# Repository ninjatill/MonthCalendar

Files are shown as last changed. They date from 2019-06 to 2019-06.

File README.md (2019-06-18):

# Month Calendar
A daily gold star system, one month at a time. Inspired by the [Every Day Calendar](https://www.kickstarter.com/projects/simonegiertz/the-every-day-calendar), this is a compact version that has 48 total touch pads.

I saw the Every Day Calendar (EDC) referenced on the Particle forums. It sounded like a great idea and I needed way to track if I took my daily allergy pill. However, the EDC is very large and therefore expensive to manufacture. It is also a big challenge (and cost) to read 365 touch inputs and control 365 LEDs (especially if made to be RGB or varying intensity). I also thought the functionality could be expanded beyond just turning an LED on to indicate completion. By the time I got around to designing my own version, the Kickstarter campain had closed and there were no resouces made available via open source yet. So I designed it all from scratch.

My Design Criteria:
- Should be small enough to fit inside a medicine cabinet or mounted on limited wall space in a bathroom.
- Should still be able to track every day of the year.
- Should record and track progress and report it to the cloud for review.
- Should be able to track multiple users (like a husband and wife pair).
- Should use capacitive touch (seems more robust and it's something new to learn).
- Should have colored LEDs that shine up through the PCB (similar to the static LED color on the EDC). Color can be used for:
  - Indicating missed days with red (or some alternative) color.
  - Showing fancy animations to entice interaction/completion.
  - Indicating separate users and tasks via differing color schemes.

Additional considerations (some after starting the design):
- There's no need to have the LEDs on all the time. Perhaps some sort of human presense detector can be incorporated to only turn on the LEDs when someone is near the system.
- If this is in a bathroom, where most people start their day, it would be benificial to act as a calendar to indicate what is the current day.
- Because of the modularity, the top touch plate (described below) could be swapped out for different configurations or locales. It might be a benifit (or neccessary) to add non-volitile storage to the touch plate to identify hardware revisions, serial numbers, locales, layout changes, etc.
- To minimize light bleed between indicators I will fabricate a 3D-printed light collimator.
- Neopixels are the obvious choice for RGB LEDs because they are chainable and have their own internal controller. I think the RGBW chips would be best so you can stil get the white LED "classic" look. Each RGBW Neopixel can draw up to 80 mA and with 48 Neopixels, the max current draw is 3.82 A. If adding day of week indicators, then with 53 Neopixels the current max current draw is up to 4.24 A. Although real-world applications would probably not push more than 2 A, the power draw is still significant and the power supply will have to be chosen appropriately. Additionally, there may have to be firmware constraints in place to prevent over taxing the power supply.

The initial design uses 2 PCBs connected via pin headers. The bottom PCB contains all the controller hardware and LEDs. The Top PCB is merely a touch plate containing all the capacitive touch pads. The microcontroller is inserted on the back-side of the controller PCB as well as the power entry ports. The PCBs will be mounted in a 3D printed case. 

# WARNING: This project is in development!
### Only v0.x files have been uploaded for review and all designs are subject to change without notice.

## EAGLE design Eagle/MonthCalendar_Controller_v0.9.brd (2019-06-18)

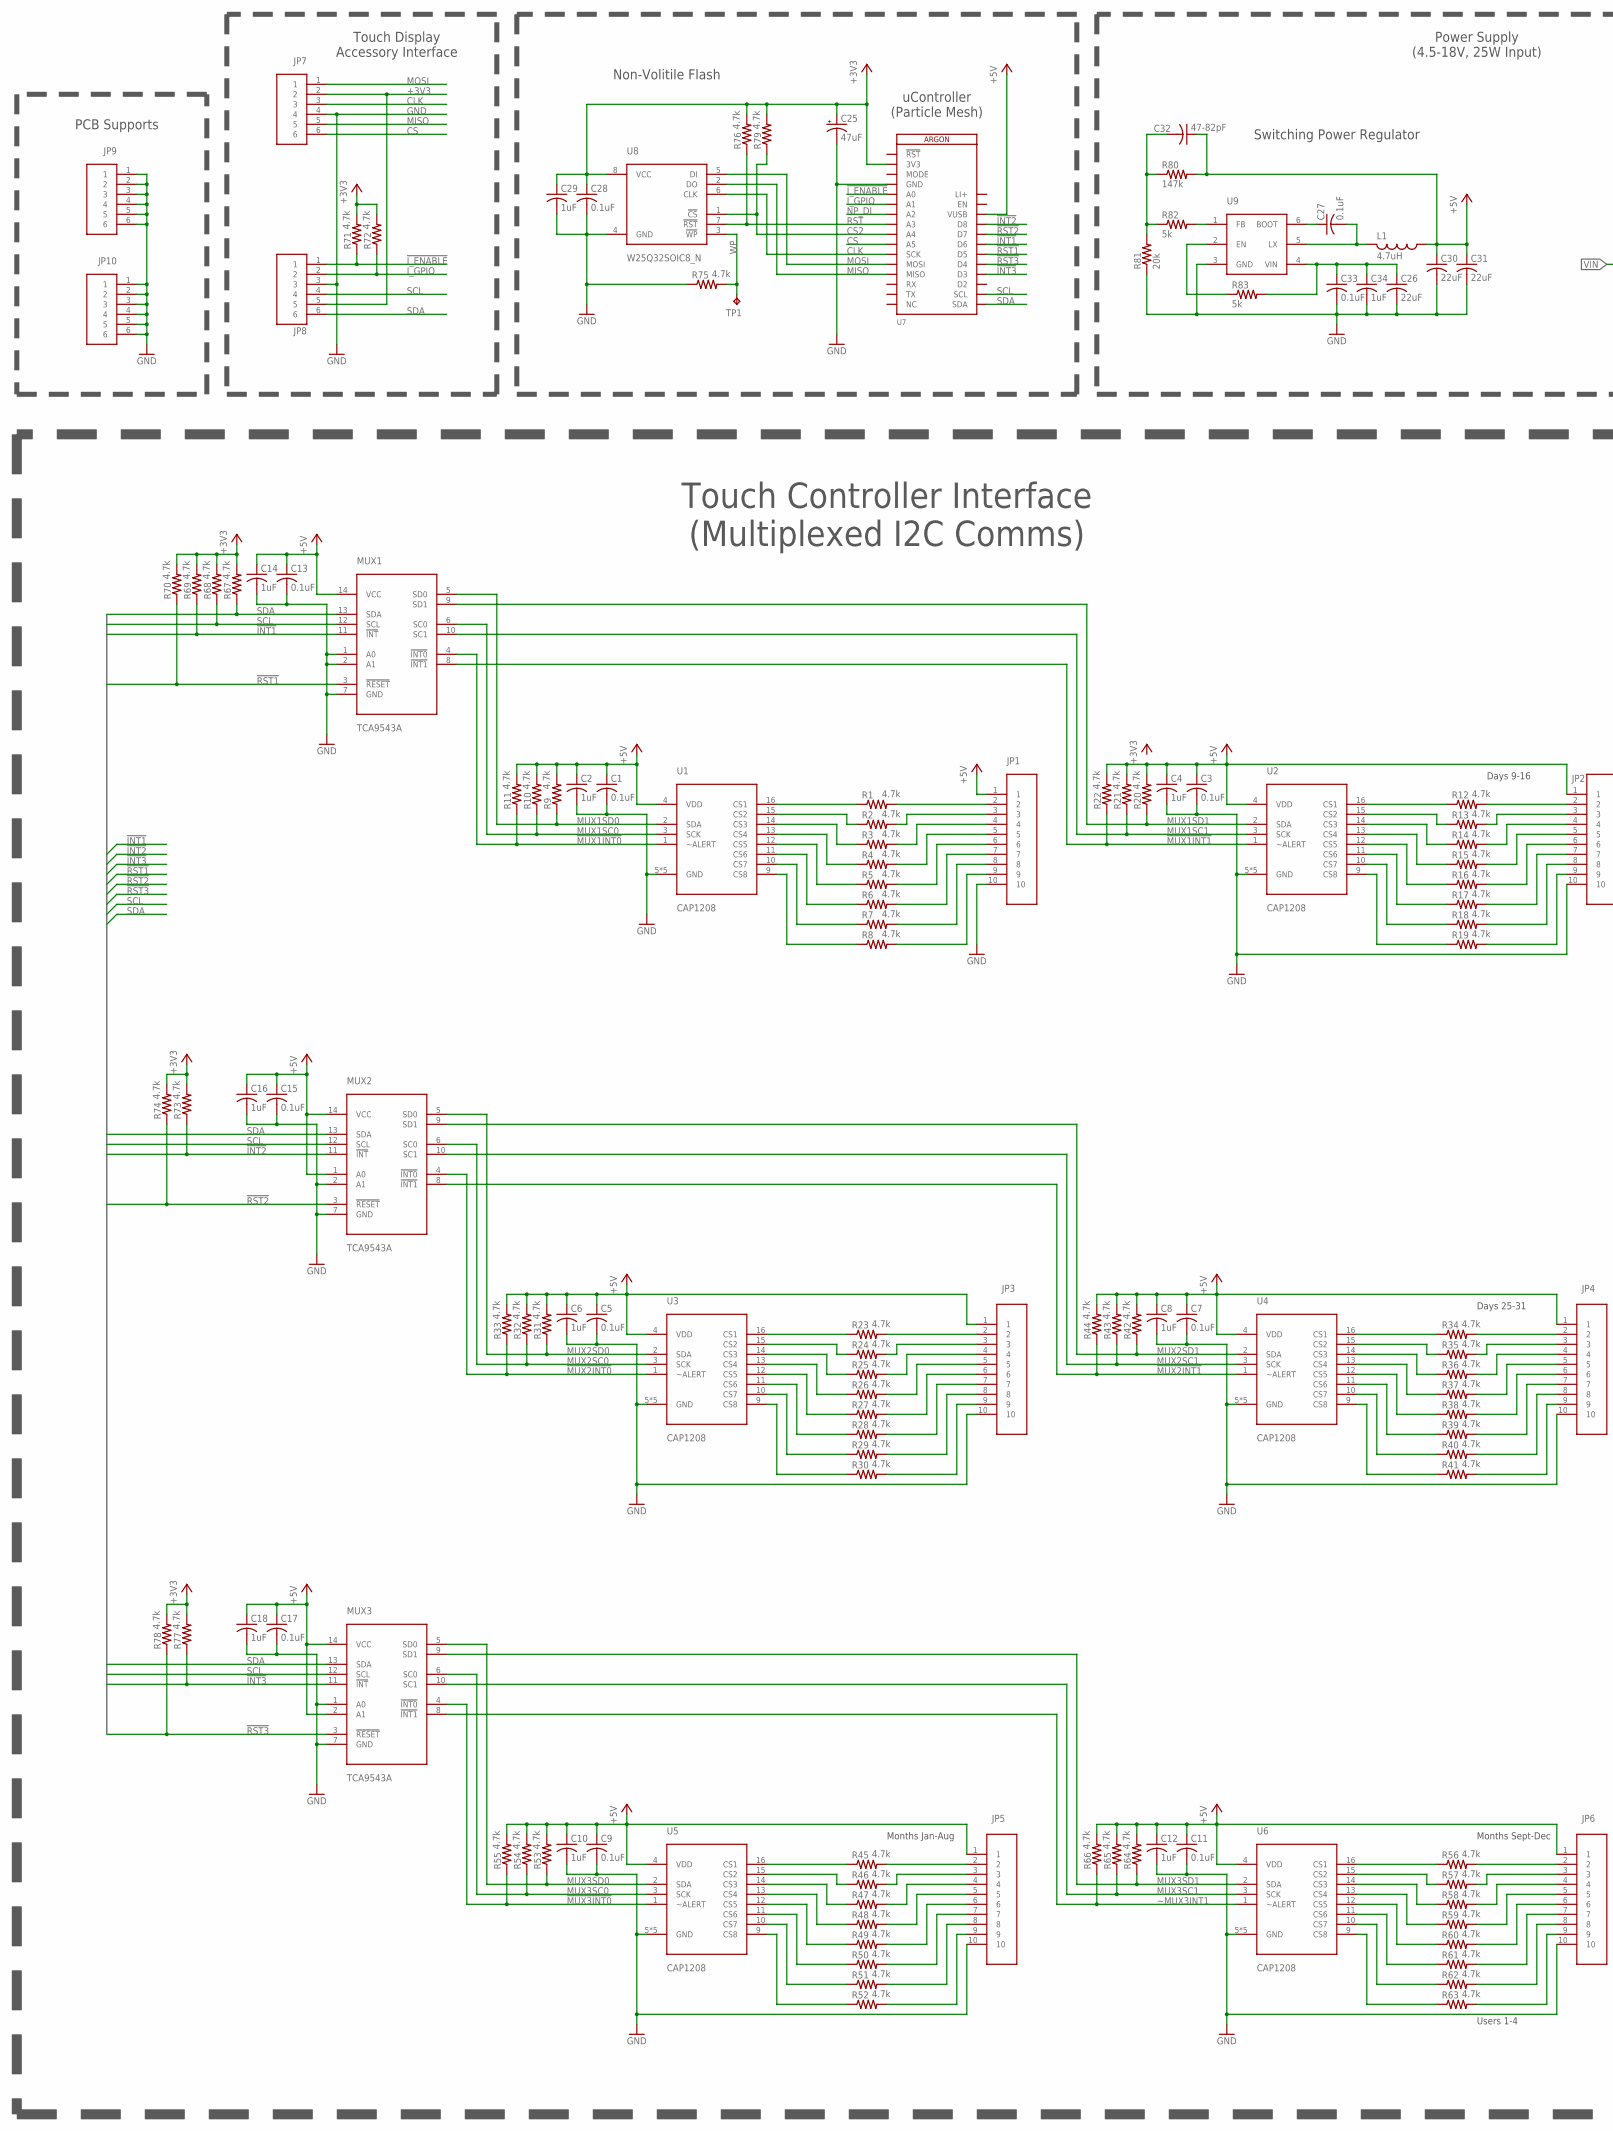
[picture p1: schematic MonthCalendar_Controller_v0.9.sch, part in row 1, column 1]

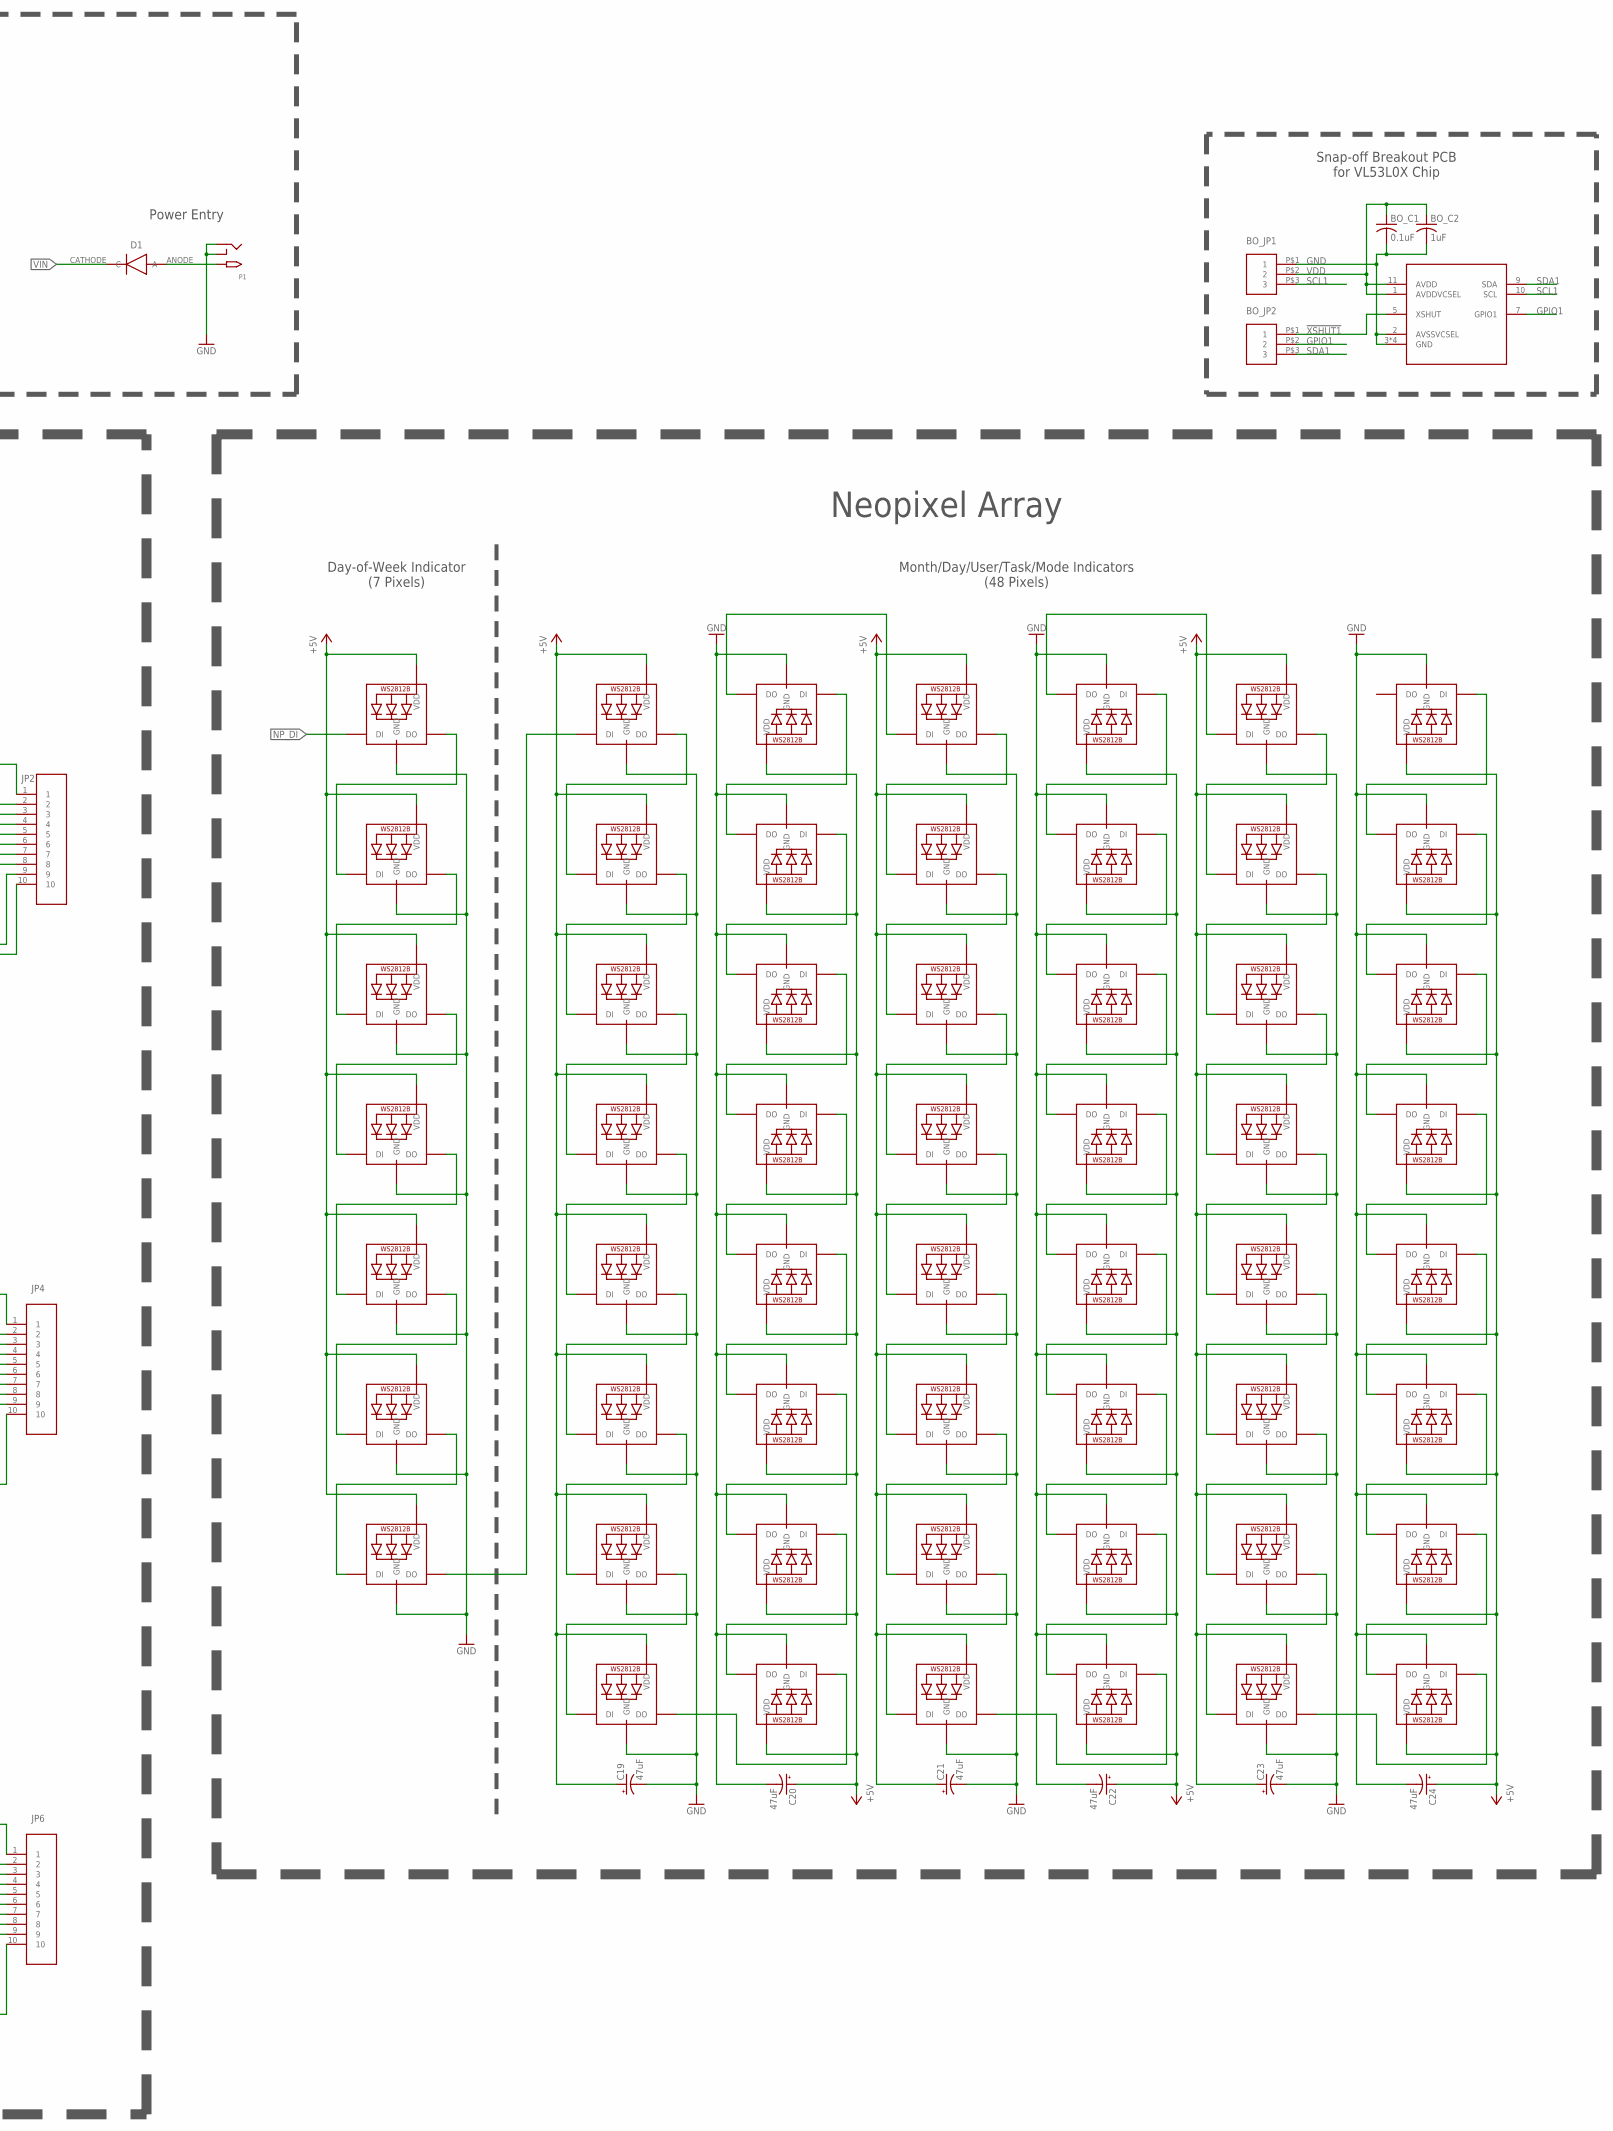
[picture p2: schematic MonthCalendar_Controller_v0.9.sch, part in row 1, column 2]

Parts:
BO_C1: 0.1uF; C0603
BO_C2: 1uF; C0603
BO_JP1, BO_JP2: PINHEAD_1X350MIL; PINHEAD_1X3_50MIL
BO_U1: VL53L0X
C1, C3, C5, C7, C9, C11, C13, C15, C17, C27, C28, C33: 0.1uF; C0603
C2, C4, C6, C8, C10, C12, C14, C16, C18, C29, C34: 1uF; C0603
C19, C20, C21, C22, C23, C24, C25: 47uF; EIA3216
C26, C30, C31: 22uF; C1206
C32: 47-82pF; C0603
D1: DIODE; SOD-128
JP1, JP2, JP3, JP4, JP5, JP6: CON_10POS_1ROWHARWIN_M3531042; CON_PINHEADER_10P_1R_TH_HARWIN_M50-3531042
JP7, JP8, JP9, JP10: CON_6POS_1ROW6P1R_M50_35306; CON_PINHEADER_6P_1R_TH_HARWIN_M50-3530642
L1: 4.7uH; 0207/5V
LED1, LED2, LED3, LED4, LED5, LED6, LED7, LED8, LED9, LED10, LED11, LED12, LED13, LED14, LED15, LED16, LED17, LED18, LED19, LED20, LED21, LED22, LED23, LED24, LED25, LED26, LED27, LED28, LED29, LED30, LED31, LED32, LED33, LED34, LED35, LED36, LED37, LED38, LED39, LED40, LED41, LED42, LED43, LED44, LED45, LED46, LED47, LED48, LED49, LED50, LED51, LED52, LED53, LED54, LED55: WS2812B5050; WS2812B
MUX1, MUX2, MUX3: TCA9543A; TSSOP-14
P1: 2.1MMJACKTHM; PJ-102A
R1, R2, R3, R4, R5, R6, R7, R8, R9, R10, R11, R12, R13, R14, R15, R16, R17, R18, R19, R20, R21, R22, R23, R24, R25, R26, R27, R28, R29, R30, R31, R32, R33, R34, R35, R36, R37, R38, R39, R40, R41, R42, R43, R44, R45, R46, R47, R48, R49, R50, R51, R52, R53, R54, R55, R56, R57, R58, R59, R60, R61, R62, R63, R64, R65, R66, R67, R68, R69, R70, R71, R72, R73, R74, R75, R76, R77, R78, R79: 4.7k; R0603
R80: 147k; R0603
R81: 20k; R0603
R82, R83: 5k; R0603
TP1: TPTP20SQ; TP20SQ
U1, U2, U3, U4, U5, U6: CAP1208; QFN-16-3X3
U7: ARGON
U8: W25Q32SOIC8_N; SOIC-8_NARROW
U9: RT6255AHGJ6FCT-ND; SOT-23-6

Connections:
!INT1: MUX1.11 (!INT), R69.1, U7.23 (D6)
!INT2: MUX2.11 (!INT), R73.1, U7.25 (D8)
!INT3: MUX3.11 (!INT), R77.1, U7.20 (D3)
!I_ENABLE: JP8.1, R71.1, U7.5 (A0)
!MUX1INT0: MUX1.4 (!INT0), R11.1, U1.1 (~ALERT)
!MUX1INT1: MUX1.8 (!INT1), R22.1, U2.1 (~ALERT)
!MUX2INT0: MUX2.4 (!INT0), R33.1, U3.1 (~ALERT)
!MUX2INT1: MUX2.8 (!INT1), R44.1, U4.1 (~ALERT)
!MUX3INT0: MUX3.4 (!INT0), R55.1, U5.1 (~ALERT)
!RST1: MUX1.3 (!RESET), R70.1, U7.22 (D5)
!RST2: MUX2.3 (!RESET), R74.1, U7.24 (D7)
!RST3: MUX3.3 (!RESET), R78.1, U7.21 (D4)
!XSHUT1: BO_JP2.P$1 (1), BO_U1.5 (XSHUT)
+3V3: C25.A (+), C28.1, C29.1, JP7.2, JP8.5, R67.2, R68.2, R69.2, R70.2, R71.2, R72.2, R73.2, R74.2, R76.2, R77.2, R78.2, R79.2, U7.2 (3V3), U8.8 (VCC)
+5V: C1.1, C2.1, C3.1, C4.1, C5.1, C6.1, C7.1, C8.1, C9.1, C10.1, C11.1, C12.1, C13.1, C14.1, C15.1, C16.1, C17.1, C18.1, C19.A (+), C20.A (+), C21.A (+), C22.A (+), C23.A (+), C24.A (+), C30.1, C31.1, C32.1, JP1.1, JP2.1, JP3.1, JP4.1, JP5.1, JP6.1, L1.1, LED1.1-VDD (VDD), LED2.1-VDD (VDD), LED3.1-VDD (VDD), LED4.1-VDD (VDD), LED5.1-VDD (VDD), LED6.1-VDD (VDD), LED7.1-VDD (VDD), LED8.1-VDD (VDD), LED9.1-VDD (VDD), LED10.1-VDD (VDD), LED11.1-VDD (VDD), LED12.1-VDD (VDD), LED13.1-VDD (VDD), LED14.1-VDD (VDD), LED15.1-VDD (VDD), LED16.1-VDD (VDD), LED17.1-VDD (VDD), LED18.1-VDD (VDD), LED19.1-VDD (VDD), LED20.1-VDD (VDD), LED21.1-VDD (VDD), LED22.1-VDD (VDD), LED23.1-VDD (VDD), LED24.1-VDD (VDD), LED25.1-VDD (VDD), LED26.1-VDD (VDD), LED27.1-VDD (VDD), LED28.1-VDD (VDD), LED29.1-VDD (VDD), LED30.1-VDD (VDD), LED31.1-VDD (VDD), LED32.1-VDD (VDD), LED33.1-VDD (VDD), LED34.1-VDD (VDD), LED35.1-VDD (VDD), LED36.1-VDD (VDD), LED37.1-VDD (VDD), LED38.1-VDD (VDD), LED39.1-VDD (VDD), LED40.1-VDD (VDD), LED41.1-VDD (VDD), LED42.1-VDD (VDD), LED43.1-VDD (VDD), LED44.1-VDD (VDD), LED45.1-VDD (VDD), LED46.1-VDD (VDD), LED47.1-VDD (VDD), LED48.1-VDD (VDD), LED49.1-VDD (VDD), LED50.1-VDD (VDD), LED51.1-VDD (VDD), LED52.1-VDD (VDD), LED53.1-VDD (VDD), LED54.1-VDD (VDD), LED55.1-VDD (VDD), MUX1.14 (VCC), MUX2.1 (A0), MUX2.14 (VCC), MUX3.2 (A1), MUX3.14 (VCC), R9.2, R10.2, R11.2, R20.2, R21.2, R22.2, R31.2, R32.2, R33.2, R42.2, R43.2, R44.2, R53.2, R54.2, R55.2, R64.2, R65.2, R66.2, R80.2, U1.4 (VDD), U2.4 (VDD), U3.4 (VDD), U4.4 (VDD), U5.4 (VDD), U6.4 (VDD), U7.26 (VUSB)
BOOT: C27.1, U9.6 (BOOT)
CLK: JP7.3, U7.11 (SCK), U8.6 (CLK)
CS: JP7.6, U7.10 (A5)
CS2: R79.1, U7.9 (A4), U8.1 (!CS)
EN: R83.1, U9.2 (EN)
FB: R82.2, U9.1 (FB)
GND: BO_C1.2, BO_C2.2, BO_JP1.P$1 (1), BO_U1.2 (AVSSVCSEL), BO_U1.3 (GND), BO_U1.4 (GND), BO_U1.6 (GND), BO_U1.12 (GND), C1.2, C2.2, C3.2, C4.2, C5.2, C6.2, C7.2, C8.2, C9.2, C10.2, C11.2, C12.2, C13.2, C14.2, C15.2, C16.2, C17.2, C18.2, C19.C (-), C20.C (-), C21.C (-), C22.C (-), C23.C (-), C24.C (-), C25.C (-), C26.2, C28.2, C29.2, C30.2, C31.2, C33.2, C34.2, JP1.10, JP2.10, JP3.10, JP4.10, JP5.10, JP6.10, JP7.4, JP8.3, JP9.1, JP9.2, JP9.3, JP9.4, JP9.5, JP9.6, JP10.1, JP10.2, JP10.3, JP10.4, JP10.5, JP10.6, LED1.3-GND (GND), LED2.3-GND (GND), LED3.3-GND (GND), LED4.3-GND (GND), LED5.3-GND (GND), LED6.3-GND (GND), LED7.3-GND (GND), LED8.3-GND (GND), LED9.3-GND (GND), LED10.3-GND (GND), LED11.3-GND (GND), LED12.3-GND (GND), LED13.3-GND (GND), LED14.3-GND (GND), LED15.3-GND (GND), LED16.3-GND (GND), LED17.3-GND (GND), LED18.3-GND (GND), LED19.3-GND (GND), LED20.3-GND (GND), LED21.3-GND (GND), LED22.3-GND (GND), LED23.3-GND (GND), LED24.3-GND (GND), LED25.3-GND (GND), LED26.3-GND (GND), LED27.3-GND (GND), LED28.3-GND (GND), LED29.3-GND (GND), LED30.3-GND (GND), LED31.3-GND (GND), LED32.3-GND (GND), LED33.3-GND (GND), LED34.3-GND (GND), LED35.3-GND (GND), LED36.3-GND (GND), LED37.3-GND (GND), LED38.3-GND (GND), LED39.3-GND (GND), LED40.3-GND (GND), LED41.3-GND (GND), LED42.3-GND (GND), LED43.3-GND (GND), LED44.3-GND (GND), LED45.3-GND (GND), LED46.3-GND (GND), LED47.3-GND (GND), LED48.3-GND (GND), LED49.3-GND (GND), LED50.3-GND (GND), LED51.3-GND (GND), LED52.3-GND (GND), LED53.3-GND (GND), LED54.3-GND (GND), LED55.3-GND (GND), MUX1.1 (A0), MUX1.2 (A1), MUX1.7 (GND), MUX2.2 (A1), MUX2.7 (GND), MUX3.1 (A0), MUX3.7 (GND), P1.RING, P1.RING_SW, R75.1, R81.1, U1.5 (GND), U1.6 (GND), U1.7 (GND), U1.8 (GND), U1.PAD (GND), U2.5 (GND), U2.6 (GND), U2.7 (GND), U2.8 (GND), U2.PAD (GND), U3.5 (GND), U3.6 (GND), U3.7 (GND), U3.8 (GND), U3.PAD (GND), U4.5 (GND), U4.6 (GND), U4.7 (GND), U4.8 (GND), U4.PAD (GND), U5.5 (GND), U5.6 (GND), U5.7 (GND), U5.8 (GND), U5.PAD (GND), U6.5 (GND), U6.6 (GND), U6.7 (GND), U6.8 (GND), U6.PAD (GND), U7.4 (GND), U8.4 (GND), U9.3 (GND)
GPIO1: BO_JP2.P$2 (2), BO_U1.7 (GPIO1)
I_GPIO: JP8.2, R72.1, U7.6 (A1)
LI+: U7.28 (LI+)
LX: C27.2, L1.2, U9.5 (LX)
MISO: JP7.5, U7.13 (MISO), U8.2 (DO)
MOSI: JP7.1, U7.12 (MOSI), U8.5 (DI)
MUX1SC0: MUX1.6 (SC0), R10.1, U1.3 (SCK)
MUX1SC1: MUX1.10 (SC1), R21.1, U2.3 (SCK)
MUX1SD0: MUX1.5 (SD0), R9.1, U1.2 (SDA)
MUX1SD1: MUX1.9 (SD1), R20.1, U2.2 (SDA)
MUX2SC0: MUX2.6 (SC0), R32.1, U3.3 (SCK)
MUX2SC1: MUX2.10 (SC1), R43.1, U4.3 (SCK)
MUX2SD0: MUX2.5 (SD0), R31.1, U3.2 (SDA)
MUX2SD1: MUX2.9 (SD1), R42.1, U4.2 (SDA)
MUX3SC0: MUX3.6 (SC0), R54.1, U5.3 (SCK)
MUX3SC1: MUX3.10 (SC1), R65.1, U6.3 (SCK)
MUX3SD0: MUX3.5 (SD0), R53.1, U5.2 (SDA)
MUX3SD1: MUX3.9 (SD1), R64.1, U6.2 (SDA)
unnamed: R1.1, U1.16 (CS1)
unnamed: JP1.2, R1.2
unnamed: JP1.3, R2.2
unnamed: R2.1, U1.15 (CS2)
unnamed: R3.1, U1.14 (CS3)
unnamed: R4.1, U1.13 (CS4)
unnamed: R5.1, U1.12 (CS5)
unnamed: R6.1, U1.11 (CS6)
unnamed: R7.1, U1.10 (CS7)
unnamed: R8.1, U1.9 (CS8)
unnamed: JP1.4, R3.2
unnamed: R12.1, U2.16 (CS1)
unnamed: R13.1, U2.15 (CS2)
unnamed: R14.1, U2.14 (CS3)
unnamed: R15.1, U2.13 (CS4)
unnamed: R16.1, U2.12 (CS5)
unnamed: R17.1, U2.11 (CS6)
unnamed: R18.1, U2.10 (CS7)
unnamed: R19.1, U2.9 (CS8)
unnamed: JP2.2, R12.2
unnamed: JP1.5, R4.2
unnamed: JP1.6, R5.2
unnamed: JP1.7, R6.2
unnamed: JP1.8, R7.2
unnamed: JP1.9, R8.2
unnamed: LED1.2-DOUT (DO), LED2.4-DIN (DI)
unnamed: LED2.2-DOUT (DO), LED3.4-DIN (DI)
unnamed: LED3.2-DOUT (DO), LED4.4-DIN (DI)
unnamed: JP2.3, R13.2
unnamed: JP2.4, R14.2
unnamed: JP2.5, R15.2
unnamed: JP2.6, R16.2
unnamed: JP2.7, R17.2
unnamed: JP2.8, R18.2
unnamed: JP2.9, R19.2
unnamed: LED4.2-DOUT (DO), LED5.4-DIN (DI)
unnamed: LED5.2-DOUT (DO), LED6.4-DIN (DI)
unnamed: LED6.2-DOUT (DO), LED7.4-DIN (DI)
unnamed: R23.1, U3.16 (CS1)
unnamed: R24.1, U3.15 (CS2)
unnamed: R25.1, U3.14 (CS3)
unnamed: R26.1, U3.13 (CS4)
unnamed: R27.1, U3.12 (CS5)
unnamed: R28.1, U3.11 (CS6)
unnamed: R29.1, U3.10 (CS7)
unnamed: R30.1, U3.9 (CS8)
unnamed: JP3.2, R23.2
unnamed: JP3.3, R24.2
unnamed: JP3.4, R25.2
unnamed: JP3.5, R26.2
unnamed: JP3.6, R27.2
unnamed: JP3.7, R28.2
unnamed: JP3.8, R29.2
unnamed: JP3.9, R30.2
unnamed: LED7.2-DOUT (DO), LED8.4-DIN (DI)
unnamed: LED9.2-DOUT (DO), LED10.4-DIN (DI)
unnamed: LED10.2-DOUT (DO), LED11.4-DIN (DI)
unnamed: R34.1, U4.16 (CS1)
unnamed: R35.1, U4.15 (CS2)
unnamed: R36.1, U4.14 (CS3)
unnamed: R37.1, U4.13 (CS4)
unnamed: R38.1, U4.12 (CS5)
unnamed: R39.1, U4.11 (CS6)
unnamed: R40.1, U4.10 (CS7)
unnamed: R41.1, U4.9 (CS8)
unnamed: JP4.2, R34.2
unnamed: JP4.3, R35.2
unnamed: JP4.4, R36.2
unnamed: JP4.5, R37.2
unnamed: JP4.6, R38.2
unnamed: JP4.7, R39.2
unnamed: JP4.8, R40.2
unnamed: JP4.9, R41.2
unnamed: LED11.2-DOUT (DO), LED12.4-DIN (DI)
unnamed: LED12.2-DOUT (DO), LED13.4-DIN (DI)
unnamed: LED13.2-DOUT (DO), LED14.4-DIN (DI)
unnamed: R45.1, U5.16 (CS1)
unnamed: R46.1, U5.15 (CS2)
unnamed: R47.1, U5.14 (CS3)
unnamed: R48.1, U5.13 (CS4)
unnamed: R49.1, U5.12 (CS5)
unnamed: R50.1, U5.11 (CS6)
unnamed: R51.1, U5.10 (CS7)
unnamed: R52.1, U5.9 (CS8)
unnamed: JP5.2, R45.2
unnamed: JP5.3, R46.2
unnamed: JP5.4, R47.2
unnamed: JP5.5, R48.2
unnamed: JP5.6, R49.2
unnamed: JP5.7, R50.2
unnamed: JP5.8, R51.2
unnamed: JP5.9, R52.2
unnamed: LED14.2-DOUT (DO), LED15.4-DIN (DI)
unnamed: LED15.2-DOUT (DO), LED16.4-DIN (DI)
unnamed: LED17.2-DOUT (DO), LED18.4-DIN (DI)
unnamed: R56.1, U6.16 (CS1)
unnamed: R57.1, U6.15 (CS2)
unnamed: R58.1, U6.14 (CS3)
unnamed: R59.1, U6.13 (CS4)
unnamed: R60.1, U6.12 (CS5)
unnamed: R61.1, U6.11 (CS6)
unnamed: R62.1, U6.10 (CS7)
unnamed: R63.1, U6.9 (CS8)
unnamed: JP6.2, R56.2
unnamed: JP6.3, R57.2
unnamed: JP6.4, R58.2
unnamed: JP6.5, R59.2
unnamed: JP6.6, R60.2
unnamed: JP6.7, R61.2
unnamed: JP6.8, R62.2
unnamed: JP6.9, R63.2
unnamed: LED18.2-DOUT (DO), LED19.4-DIN (DI)
unnamed: LED19.2-DOUT (DO), LED20.4-DIN (DI)
unnamed: LED20.2-DOUT (DO), LED21.4-DIN (DI)
unnamed: LED21.2-DOUT (DO), LED22.4-DIN (DI)
unnamed: LED22.2-DOUT (DO), LED23.4-DIN (DI)
unnamed: LED23.2-DOUT (DO), LED24.4-DIN (DI)
unnamed: LED25.2-DOUT (DO), LED26.4-DIN (DI)
unnamed: LED26.2-DOUT (DO), LED27.4-DIN (DI)
unnamed: LED27.2-DOUT (DO), LED28.4-DIN (DI)
unnamed: LED28.2-DOUT (DO), LED29.4-DIN (DI)
unnamed: LED29.2-DOUT (DO), LED30.4-DIN (DI)
unnamed: LED30.2-DOUT (DO), LED31.4-DIN (DI)
unnamed: LED31.2-DOUT (DO), LED32.4-DIN (DI)
unnamed: LED33.2-DOUT (DO), LED34.4-DIN (DI)
unnamed: LED34.2-DOUT (DO), LED35.4-DIN (DI)
unnamed: LED35.2-DOUT (DO), LED36.4-DIN (DI)
unnamed: LED36.2-DOUT (DO), LED37.4-DIN (DI)
unnamed: LED37.2-DOUT (DO), LED38.4-DIN (DI)
unnamed: LED38.2-DOUT (DO), LED39.4-DIN (DI)
unnamed: LED39.2-DOUT (DO), LED40.4-DIN (DI)
unnamed: LED41.2-DOUT (DO), LED42.4-DIN (DI)
unnamed: LED42.2-DOUT (DO), LED43.4-DIN (DI)
unnamed: LED43.2-DOUT (DO), LED44.4-DIN (DI)
unnamed: LED44.2-DOUT (DO), LED45.4-DIN (DI)
unnamed: LED45.2-DOUT (DO), LED46.4-DIN (DI)
unnamed: LED46.2-DOUT (DO), LED47.4-DIN (DI)
unnamed: LED47.2-DOUT (DO), LED48.4-DIN (DI)
unnamed: LED8.2-DOUT (DO), LED9.4-DIN (DI)
unnamed: LED24.2-DOUT (DO), LED25.4-DIN (DI)
unnamed: LED40.2-DOUT (DO), LED41.4-DIN (DI)
unnamed: LED16.2-DOUT (DO), LED17.4-DIN (DI)
unnamed: LED32.2-DOUT (DO), LED33.4-DIN (DI)
unnamed: LED49.2-DOUT (DO), LED50.4-DIN (DI)
unnamed: LED50.2-DOUT (DO), LED51.4-DIN (DI)
unnamed: LED51.2-DOUT (DO), LED52.4-DIN (DI)
unnamed: LED52.2-DOUT (DO), LED53.4-DIN (DI)
unnamed: LED53.2-DOUT (DO), LED54.4-DIN (DI)
unnamed: LED54.2-DOUT (DO), LED55.4-DIN (DI)
unnamed: LED1.4-DIN (DI), LED55.2-DOUT (DO)
unnamed: C32.2, R80.1, R81.2, R82.1
NP_DI: LED49.4-DIN (DI), U7.7 (A2)
RST: R76.1, U7.8 (A3), U8.7 (!RST)
SCL: JP8.4, MUX1.12 (SCL), MUX2.12 (SCL), MUX3.12 (SCL), R68.1, U7.18 (SCL)
SCL1: BO_JP1.P$3 (3), BO_U1.10 (SCL)
SDA: JP8.6, MUX1.13 (SDA), MUX2.13 (SDA), MUX3.13 (SDA), R67.1, U7.17 (SDA)
SDA1: BO_JP2.P$3 (3), BO_U1.9 (SDA)
VDD: BO_C1.1, BO_C2.1, BO_JP1.P$2 (2), BO_U1.1 (AVDDVCSEL), BO_U1.11 (AVDD)
VIN: C26.1, C33.1, C34.1, D1.CATHODE (C), R83.2, U9.4 (VIN)
VPORT: D1.ANODE (A), P1.TIP
WP: R75.2, TP1.TP, U8.3 (!WP)
~MUX3INT1: MUX3.8 (!INT1), R66.1, U6.1 (~ALERT)

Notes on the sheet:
Days 9-16
Days 25-31
Months Jan-Aug
Months Sept-Dec
Users 1-4
Power Entry
uController (Particle Mesh)
Touch Display Accessory Interface
Snap-off Breakout PCB for VL53L0X Chip
Neopixel Array
Day-of-Week Indicator (7 Pixels)
Month/Day/User/Task/Mode Indicators (48 Pixels)
Touch Controller Interface (Multiplexed I2C Comms)
Non-Volitile Flash
PCB Supports
Switching Power Regulator
Power Supply (4.5-18V, 25W Input)

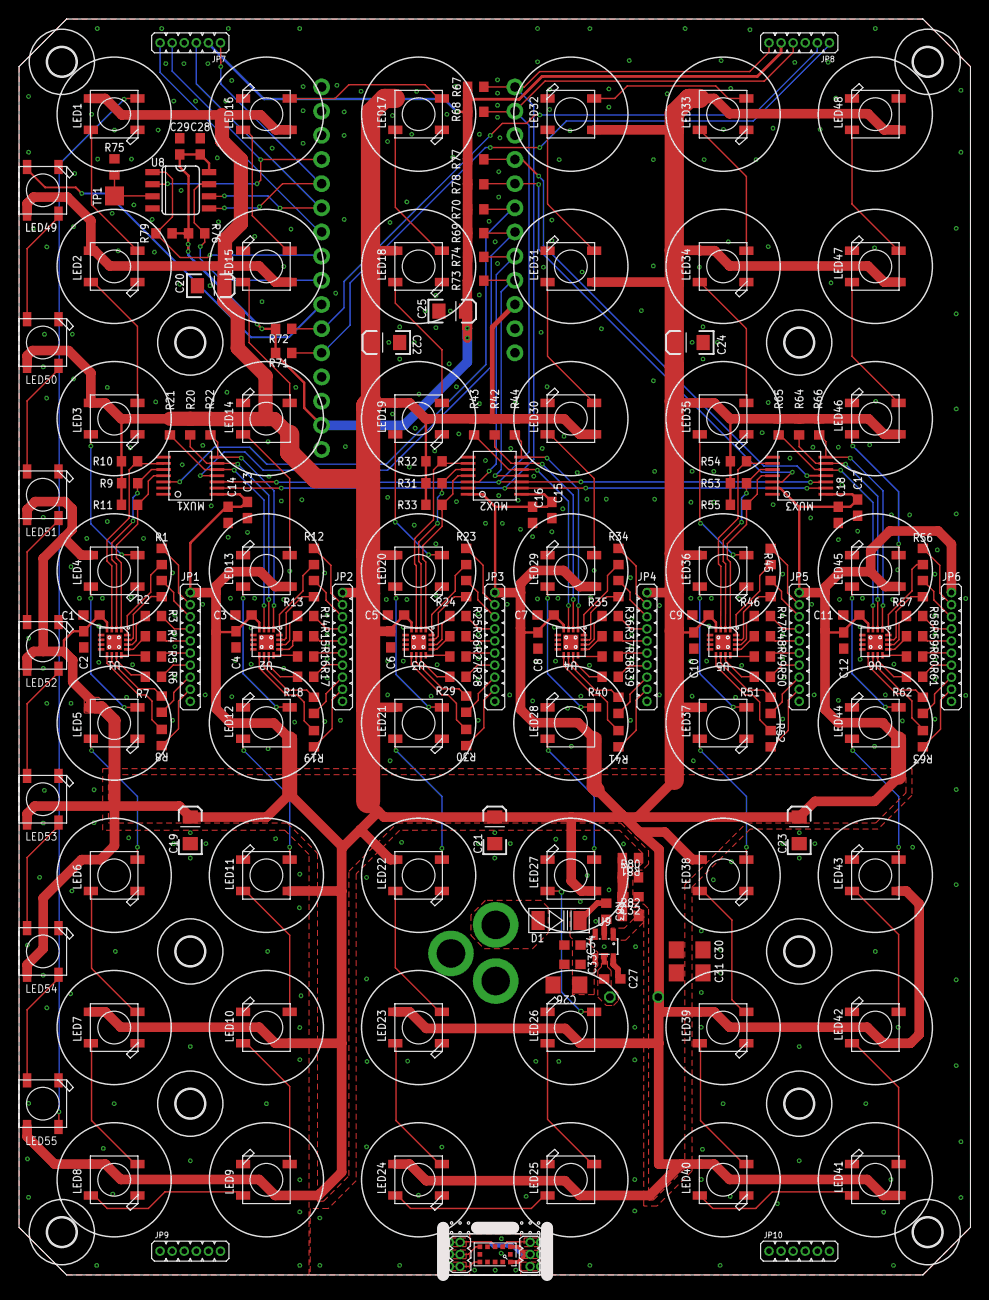
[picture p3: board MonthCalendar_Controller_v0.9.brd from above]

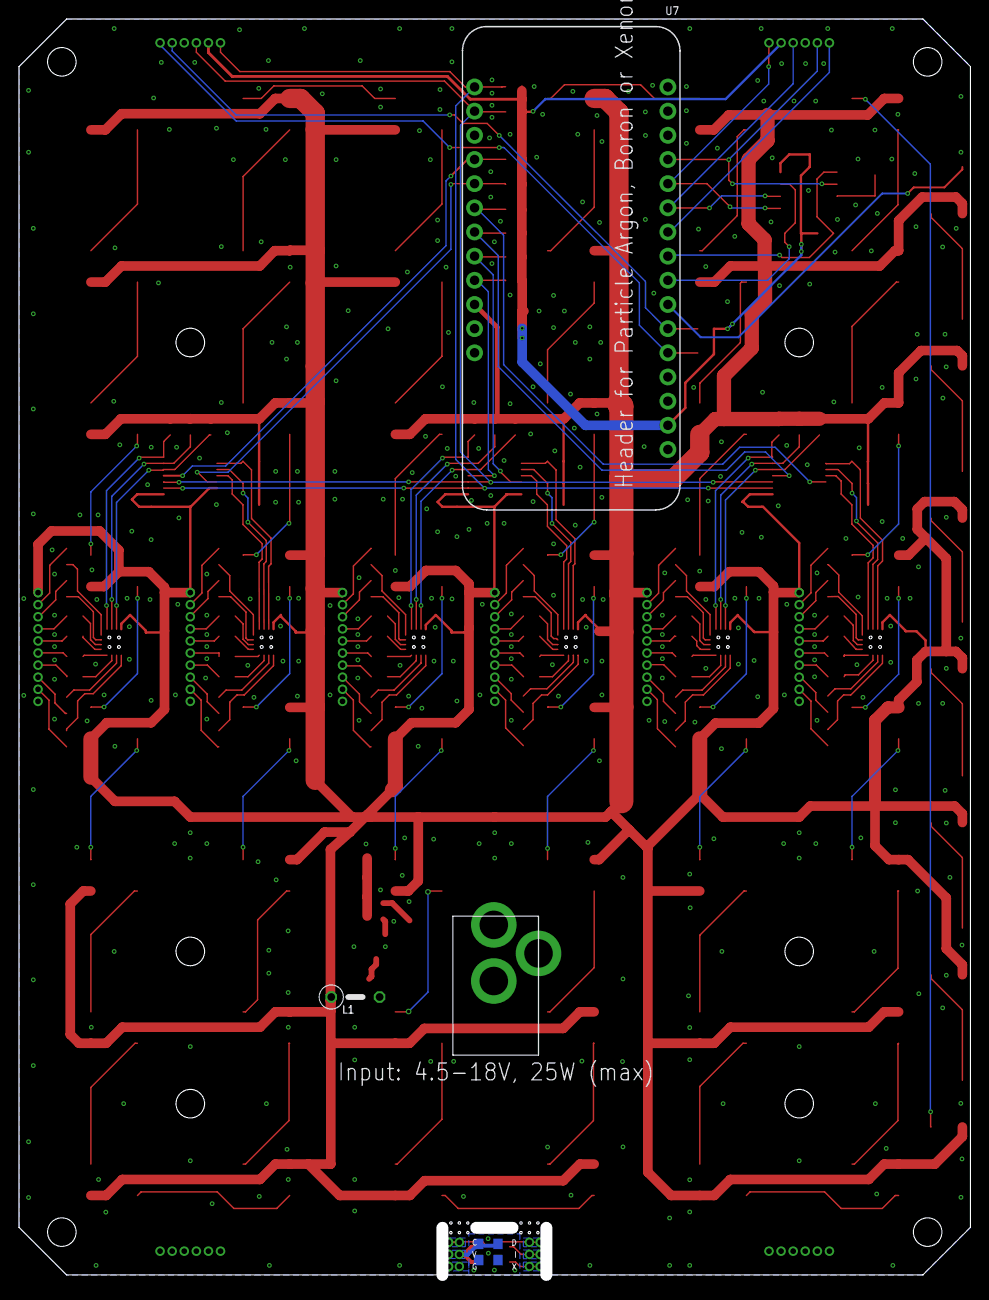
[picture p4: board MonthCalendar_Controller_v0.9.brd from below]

Board: 2 copper layers, 100.0 x 132.0 mm, 261 parts (5 on the bottom side), 201 nets.

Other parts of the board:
U$1, U$2, U$3, U$4, U$5, U$6, U$7, U$8, U$9, U$10, U$11, U$12, U$13, U$14, U$15, U$16, U$17, U$18, U$19, U$20, U$21, U$22, U$23, U$24, U$25, U$26, U$27, U$28, U$29, U$30, U$31, U$32, U$33, U$34, U$35, U$36, U$37, U$38, U$39, U$40, U$41, U$42, U$43, U$44, U$45, U$46, U$47, U$48: PAD_CAPACITIVETOUCH_2_OUTLINE
U$49, U$50, U$51, U$52, U$53, U$54, U$55, U$56, U$57, U$58: 3,0

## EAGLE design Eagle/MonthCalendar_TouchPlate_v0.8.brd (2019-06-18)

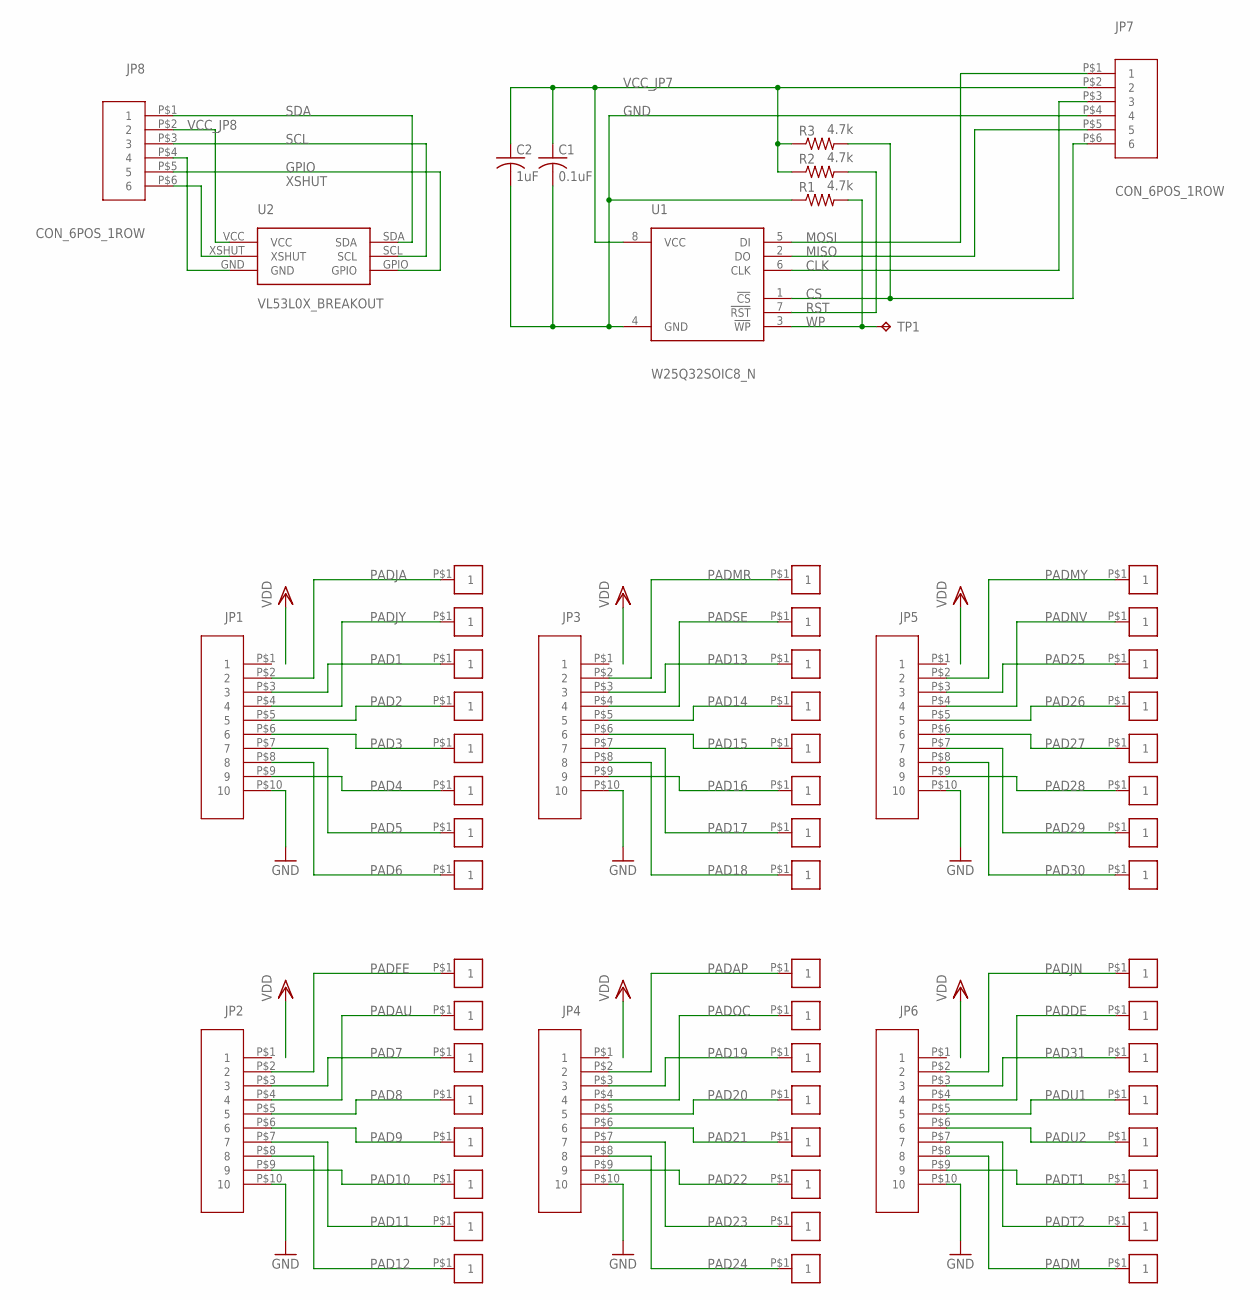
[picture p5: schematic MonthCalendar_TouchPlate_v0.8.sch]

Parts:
C1: 0.1uF; C0603
C2: 1uF; C0603
JP1, JP2, JP3, JP4, JP5, JP6: CON_10POS_1ROWHARWIN_M50-3141045_N; CON_RECPT_10P_1R_SMD_HARWIN_M50-3141045_NARROW
JP7, JP8: CON_6POS_1ROW; CON_RECPT_6P_1R_SMD_HARWIN_M50-3141045_NARROW
R1, R2, R3: 4.7k; R0603
TP1: TPTP20SQ; TP20SQ
U1: W25Q32SOIC8_N; SOIC-8_NARROW
U2: VL53L0X_BREAKOUT; VL53L0X_BREAKOUT_THROUGHPCB
U$1, U$2, U$3, U$4, U$5, U$6, U$7, U$8, U$9, U$10, U$11, U$12, U$13, U$14, U$15, U$16, U$17, U$18, U$19, U$20, U$21, U$22, U$23, U$24, U$25, U$26, U$27, U$28, U$29, U$30, U$31, U$32, U$33, U$34, U$35, U$36, U$37, U$38, U$39, U$40, U$41, U$42, U$43, U$44, U$45, U$46, U$47, U$48: PAD_CAPACITIVETOUCHV4; PAD_CAPACITIVETOUCH_4

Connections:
CLK: JP7.P$3 (3), U1.6 (CLK)
CS: JP7.P$6 (6), R3.2, U1.1 (!CS)
GND: C1.2, C2.2, JP1.P$10 (10), JP2.P$10 (10), JP3.P$10 (10), JP4.P$10 (10), JP5.P$10 (10), JP6.P$10 (10), JP7.P$4 (4), JP8.P$4 (4), R1.1, U1.4 (GND), U2.GND
GPIO: JP8.P$5 (5), U2.GPIO
MISO: JP7.P$5 (5), U1.2 (DO)
MOSI: JP7.P$1 (1), U1.5 (DI)
PAD1: JP1.P$3 (3), U$3.P$1
PAD2: JP1.P$5 (5), U$4.P$1
PAD3: JP1.P$6 (6), U$5.P$1
PAD4: JP1.P$9 (9), U$6.P$1
PAD5: JP1.P$7 (7), U$7.P$1
PAD6: JP1.P$8 (8), U$8.P$1
PAD7: JP2.P$3 (3), U$11.P$1
PAD8: JP2.P$5 (5), U$12.P$1
PAD9: JP2.P$6 (6), U$13.P$1
PAD10: JP2.P$9 (9), U$14.P$1
PAD11: JP2.P$7 (7), U$15.P$1
PAD12: JP2.P$8 (8), U$16.P$1
PAD13: JP3.P$3 (3), U$19.P$1
PAD14: JP3.P$5 (5), U$20.P$1
PAD15: JP3.P$6 (6), U$21.P$1
PAD16: JP3.P$9 (9), U$22.P$1
PAD17: JP3.P$7 (7), U$23.P$1
PAD18: JP3.P$8 (8), U$24.P$1
PAD19: JP4.P$3 (3), U$27.P$1
PAD20: JP4.P$5 (5), U$28.P$1
PAD21: JP4.P$6 (6), U$29.P$1
PAD22: JP4.P$9 (9), U$30.P$1
PAD23: JP4.P$7 (7), U$31.P$1
PAD24: JP4.P$8 (8), U$32.P$1
PAD25: JP5.P$3 (3), U$35.P$1
PAD26: JP5.P$5 (5), U$36.P$1
PAD27: JP5.P$6 (6), U$37.P$1
PAD28: JP5.P$9 (9), U$38.P$1
PAD29: JP5.P$7 (7), U$39.P$1
PAD30: JP5.P$8 (8), U$40.P$1
PAD31: JP6.P$3 (3), U$43.P$1
PADAP: JP4.P$2 (2), U$25.P$1
PADAU: JP2.P$4 (4), U$10.P$1
PADDE: JP6.P$4 (4), U$42.P$1
PADFE: JP2.P$2 (2), U$9.P$1
PADJA: JP1.P$2 (2), U$1.P$1
PADJN: JP6.P$2 (2), U$41.P$1
PADJY: JP1.P$4 (4), U$2.P$1
PADM: JP6.P$8 (8), U$48.P$1
PADMR: JP3.P$2 (2), U$17.P$1
PADMY: JP5.P$2 (2), U$33.P$1
PADNV: JP5.P$4 (4), U$34.P$1
PADOC: JP4.P$4 (4), U$26.P$1
PADSE: JP3.P$4 (4), U$18.P$1
PADT1: JP6.P$9 (9), U$46.P$1
PADT2: JP6.P$7 (7), U$47.P$1
PADU1: JP6.P$5 (5), U$44.P$1
PADU2: JP6.P$6 (6), U$45.P$1
RST: R2.2, U1.7 (!RST)
SCL: JP8.P$3 (3), U2.SCL
SDA: JP8.P$1 (1), U2.SDA
VCC_JP7: C1.1, C2.1, JP7.P$2 (2), R2.1, R3.1, U1.8 (VCC)
VCC_JP8: JP8.P$2 (2), U2.VCC
WP: R1.2, TP1.TP, U1.3 (!WP)
XSHUT: JP8.P$6 (6), U2.XSHUT

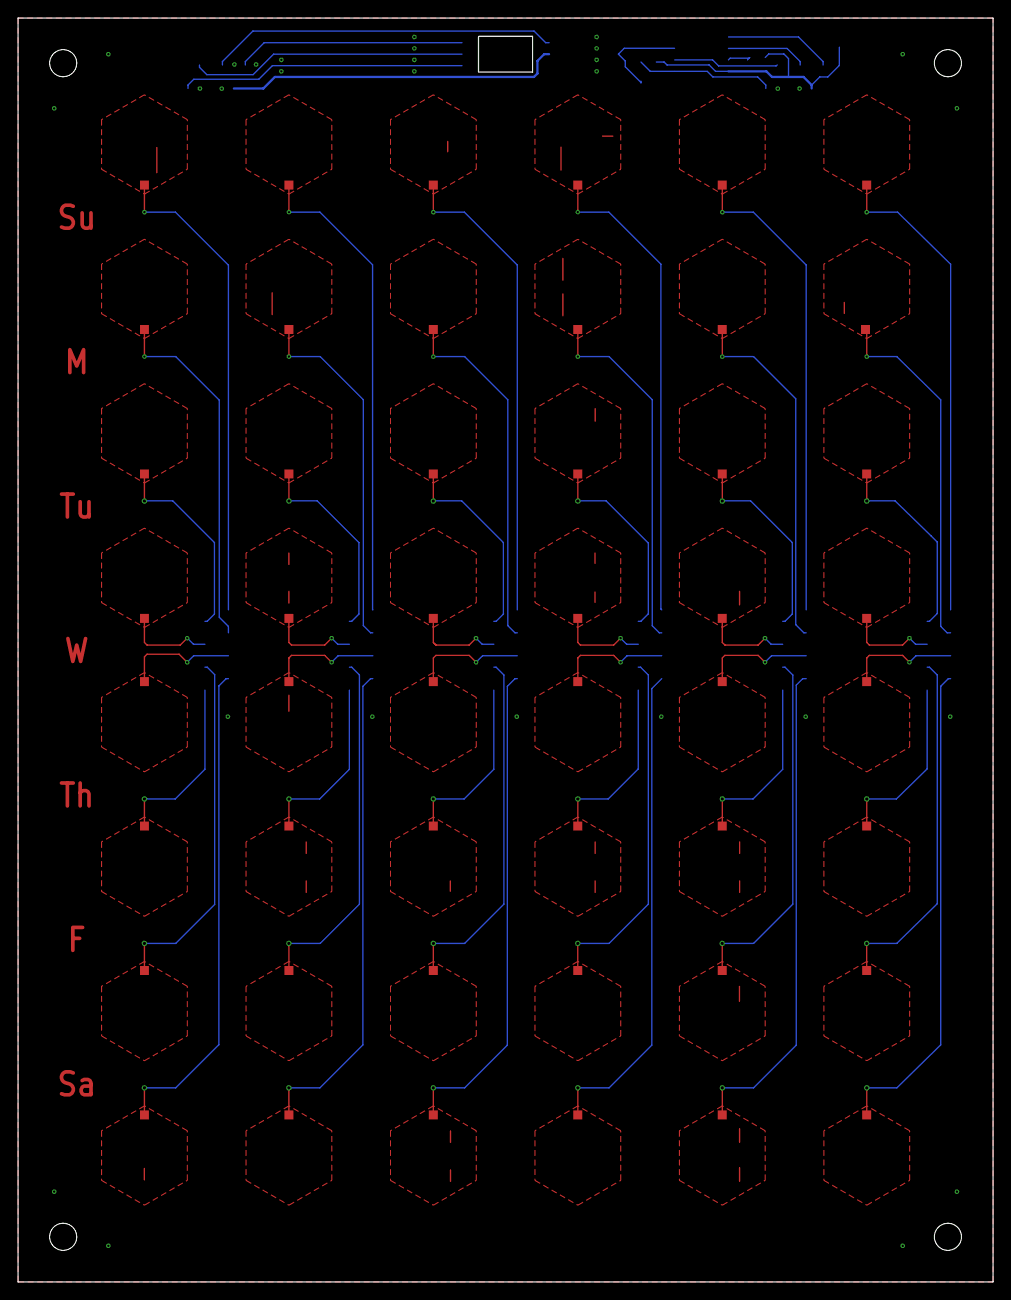
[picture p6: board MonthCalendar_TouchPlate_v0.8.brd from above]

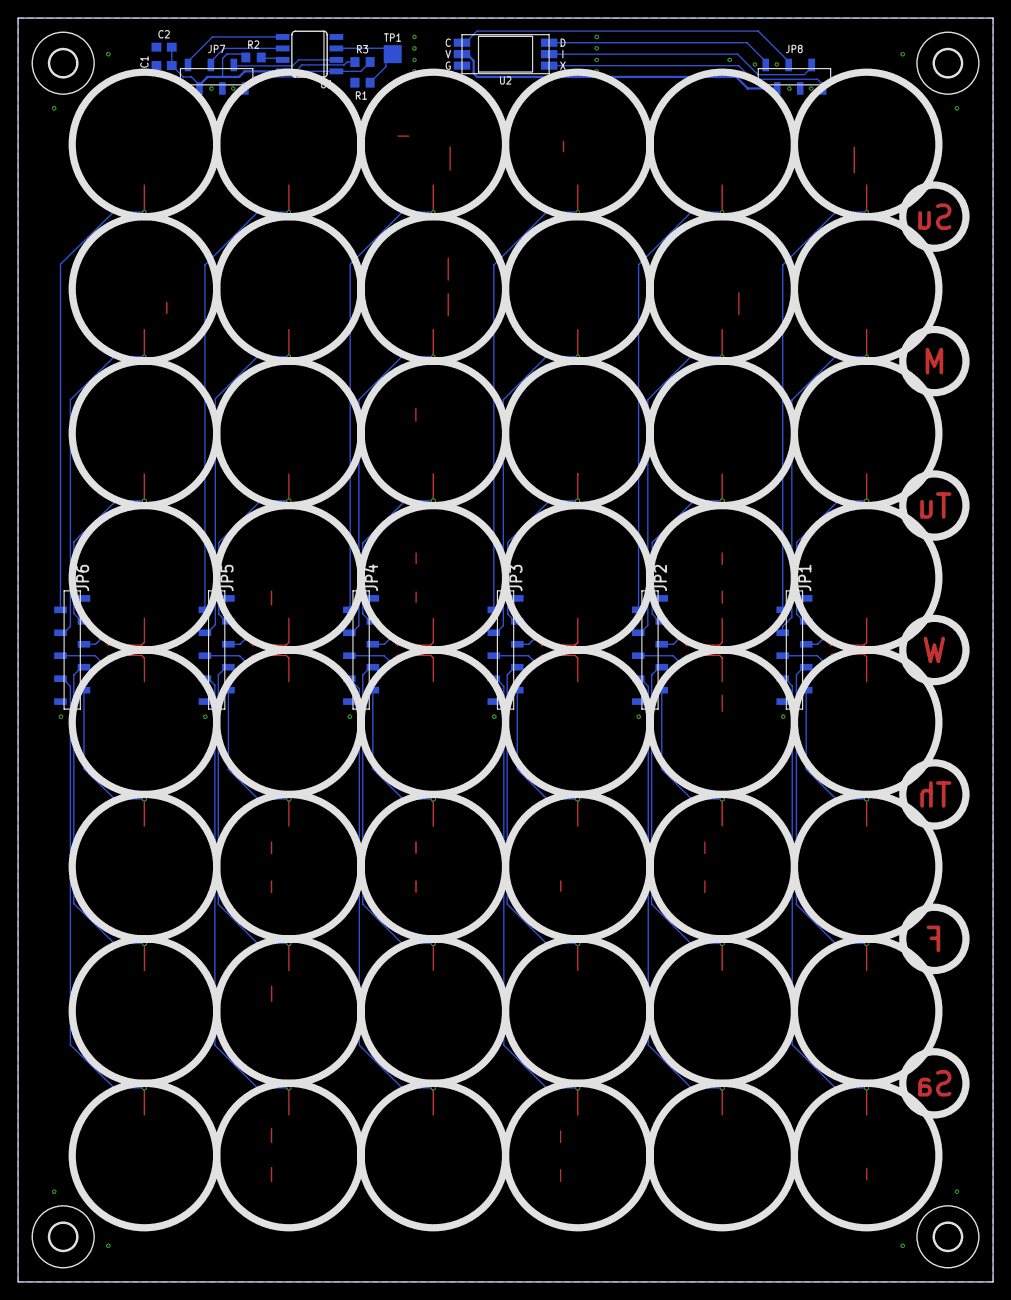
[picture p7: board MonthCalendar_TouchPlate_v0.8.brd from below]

Board: 2 copper layers, 108.0 x 140.0 mm, 68 parts (20 on the bottom side), 61 nets.

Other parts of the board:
HOLE_TL: 3,0
U$50, U$51, U$52: 3,0

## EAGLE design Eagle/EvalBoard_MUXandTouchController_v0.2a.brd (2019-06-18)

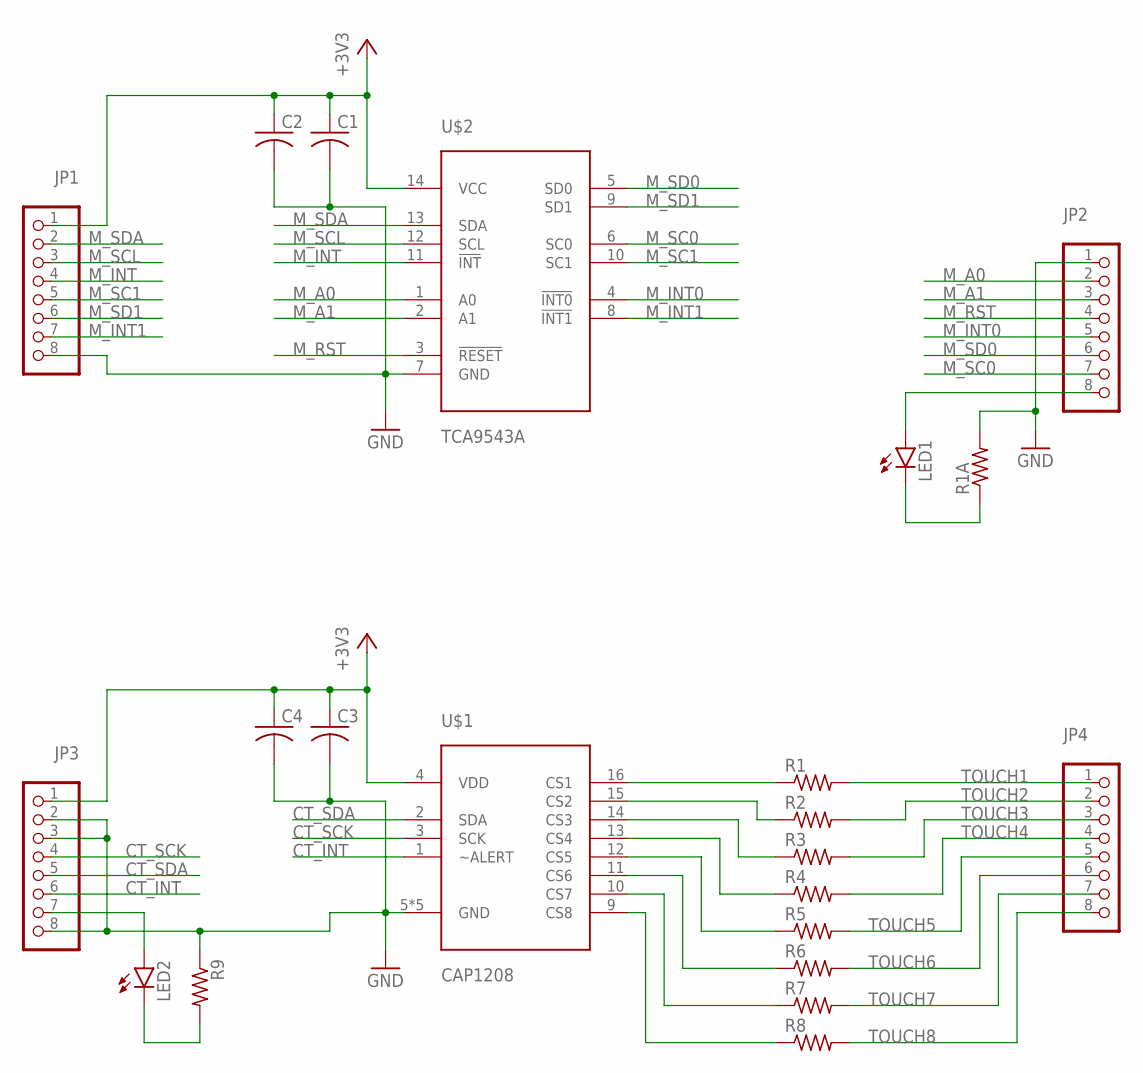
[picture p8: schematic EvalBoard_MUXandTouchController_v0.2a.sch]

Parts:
C1, C2, C3, C4: C-USC0603; C0603
JP1, JP2, JP3, JP4: PINHD-1X8BIG; 1X08-BIG
LED1, LED2: LEDCHIP-LED0603; CHIP-LED0603
R1, R1A, R2, R3, R4, R5, R6, R7, R8, R9: R-US_R0603; R0603
U$1: CAP1208; QFN-16-3X3
U$2: TCA9543A; TSSOP-14

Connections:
+3V3: C1.1, C2.1, C3.1, C4.1, JP1.1, JP3.1, U$1.4 (VDD), U$2.14 (VCC)
CT_INT: JP3.6, U$1.1 (~ALERT)
CT_SCK: JP3.4, U$1.3 (SCK)
CT_SDA: JP3.5, U$1.2 (SDA)
GND: C1.2, C2.2, C3.2, C4.2, JP1.8, JP2.1, JP3.2, JP3.3, JP3.8, R1A.2, R9.1, U$1.5 (GND), U$1.6 (GND), U$1.7 (GND), U$1.8 (GND), U$1.PAD (GND), U$2.7 (GND)
M_A0: JP2.2, U$2.1 (A0)
M_A1: JP2.3, U$2.2 (A1)
M_INT: JP1.4, U$2.11 (!INT)
M_INT0: JP2.5, U$2.4 (!INT0)
M_INT1: JP1.7, U$2.8 (!INT1)
M_RST: JP2.4, U$2.3 (!RESET)
M_SC0: JP2.7, U$2.6 (SC0)
M_SC1: JP1.5, U$2.10 (SC1)
M_SCL: JP1.3, U$2.12 (SCL)
M_SD0: JP2.6, U$2.5 (SD0)
M_SD1: JP1.6, U$2.9 (SD1)
M_SDA: JP1.2, U$2.13 (SDA)
unnamed: R1.1, U$1.16 (CS1)
unnamed: JP3.7, LED2.A
unnamed: R2.1, U$1.15 (CS2)
unnamed: LED2.C, R9.2
unnamed: JP2.8, LED1.A
unnamed: LED1.C, R1A.1
unnamed: R3.1, U$1.14 (CS3)
unnamed: R4.1, U$1.13 (CS4)
unnamed: R5.1, U$1.12 (CS5)
unnamed: R6.1, U$1.11 (CS6)
unnamed: R7.1, U$1.10 (CS7)
unnamed: R8.1, U$1.9 (CS8)
TOUCH1: JP4.1, R1.2
TOUCH2: JP4.2, R2.2
TOUCH3: JP4.3, R3.2
TOUCH4: JP4.4, R4.2
TOUCH5: JP4.5, R5.2
TOUCH6: JP4.6, R6.2
TOUCH7: JP4.7, R7.2
TOUCH8: JP4.8, R8.2

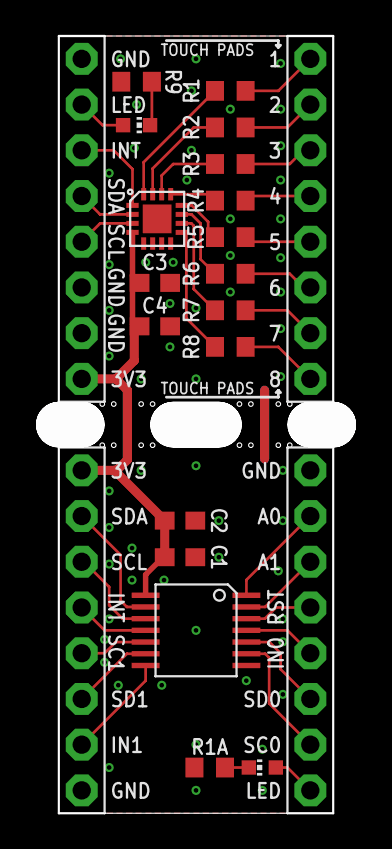
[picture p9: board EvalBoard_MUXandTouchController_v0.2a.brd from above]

Board: 2 copper layers, 15.2 x 43.2 mm, 22 parts (0 on the bottom side), 37 nets.

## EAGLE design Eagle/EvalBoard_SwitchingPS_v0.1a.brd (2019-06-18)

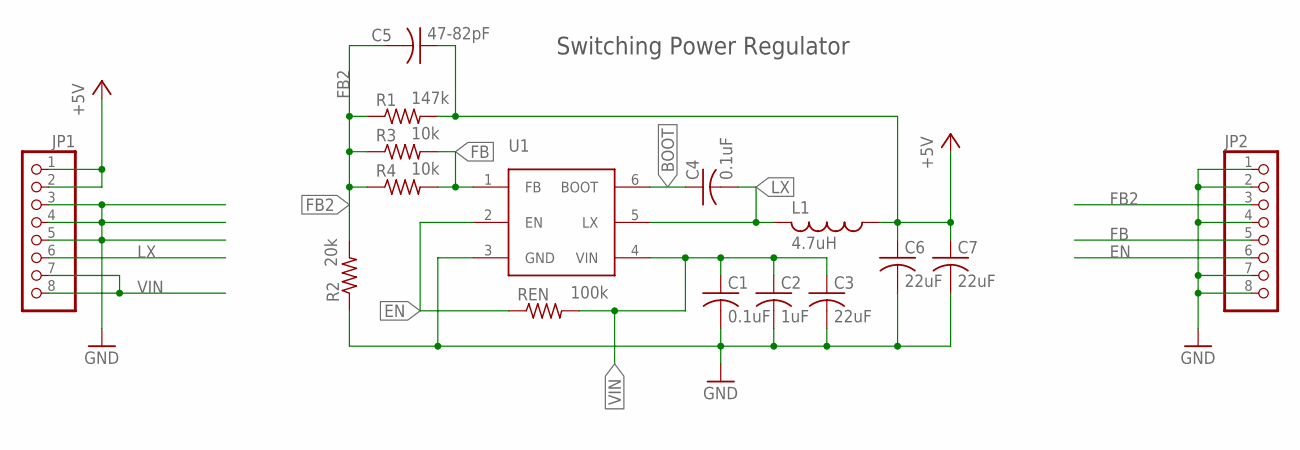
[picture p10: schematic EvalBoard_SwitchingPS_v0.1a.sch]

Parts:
C1, C4: 0.1uF; C0603
C2: 1uF; C0603
C3, C6, C7: 22uF; C1206
C5: 47-82pF; C0603
JP1, JP2: PINHD-1X8BIG; 1X08-BIG
L1: 4.7uH; 0207/15
R1: 147k; R0603
R2: 20k; R0603
R3, R4: 10k; R0603
REN: 100k; R0603
U1: RT6255AHGJ6FCT-ND; SOT-23-6

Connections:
+5V: C5.1, C6.1, C7.1, JP1.1, JP1.2, L1.1, R1.2
BOOT: C4.1, U1.6 (BOOT)
EN: JP2.6, REN.1, U1.2 (EN)
FB: JP2.5, R3.2, R4.2, U1.1 (FB)
FB2: C5.2, JP2.3, R1.1, R2.2, R3.1, R4.1
GND: C1.2, C2.2, C3.2, C6.2, C7.2, JP1.3, JP1.4, JP1.5, JP2.1, JP2.2, JP2.4, JP2.7, JP2.8, R2.1, U1.3 (GND)
LX: C4.2, JP1.6, L1.2, U1.5 (LX)
VIN: C1.1, C2.1, C3.1, JP1.7, JP1.8, REN.2, U1.4 (VIN)

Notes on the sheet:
Switching Power Regulator

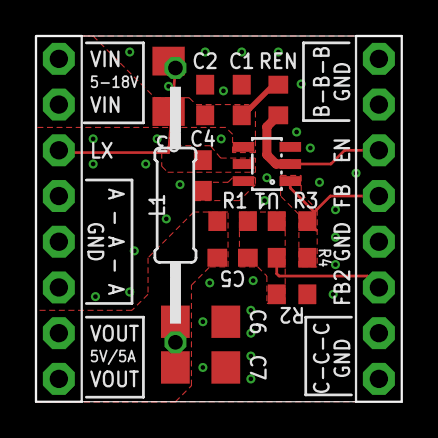
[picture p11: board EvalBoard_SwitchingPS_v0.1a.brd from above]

Board: 2 copper layers, 20.3 x 20.3 mm, 16 parts (0 on the bottom side), 8 nets.

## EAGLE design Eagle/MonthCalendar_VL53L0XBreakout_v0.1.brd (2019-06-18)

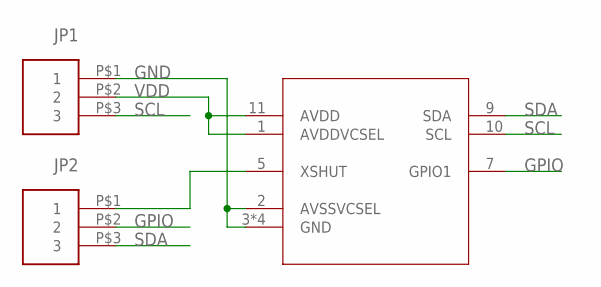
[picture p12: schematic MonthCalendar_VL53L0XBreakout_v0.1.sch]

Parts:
JP1, JP2: PINHEAD_1X350MIL; PINHEAD_1X3_50MIL
U1: VL53L0X

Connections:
GND: JP1.P$1 (1), U1.2 (AVSSVCSEL), U1.3 (GND), U1.4 (GND), U1.6 (GND), U1.12 (GND)
GPIO: JP2.P$2 (2), U1.7 (GPIO1)
SCL: JP1.P$3 (3), U1.10 (SCL)
SDA: JP2.P$3 (3), U1.9 (SDA)
VDD: JP1.P$2 (2), U1.1 (AVDDVCSEL), U1.11 (AVDD)
XSHUT: JP2.P$1 (1), U1.5 (XSHUT)


Board: 2 copper layers, 10.9 x 4.3 mm, 3 parts (0 on the bottom side), 6 nets.

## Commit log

2019-06-18 Initial Commit
    Added all v0.x files for controller, touch plate and evaluation breadout boards.
    [EvalBoard_MUXandTouchController_v0.2a.brd, EvalBoard_MUXandTouchController_v0.2a.sch, EvalBoard_SwitchingPS_v0.1a.brd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]
2019-06-18 Added controller files v0.9
    Added controller files v0.9
    [MonthCalendar_Controller_v0.9.brd, MonthCalendar_Controller_v0.9.sch]

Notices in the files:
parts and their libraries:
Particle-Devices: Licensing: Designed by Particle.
